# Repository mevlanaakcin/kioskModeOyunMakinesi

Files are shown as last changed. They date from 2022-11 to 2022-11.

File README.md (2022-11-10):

# kioskModeOyunMakinesi
Kiosk Modda çalışan eğlence amaçlı oyun makinesi<br>
<h3>PCB Tasarımı</h3><br>
Elektronik devre şeması ve PCB board tasarımı Eagle de tasarlandı.<br>





<h3>Yazılım</h3><br>
Yalım bölümü Atmega328-P işlemci kullanıldığından Raspberrypi ile tasarlanan kart arasında Serial haberleşme yapılmıştır. Kart üzerinde bulunan servo motorlar ile ödül dağıtım kanallarını kontrol edilmektedir. Görsel amaçlı kullanılan neopiksellerin yazılımsal kontrolleride yapılmıştır.

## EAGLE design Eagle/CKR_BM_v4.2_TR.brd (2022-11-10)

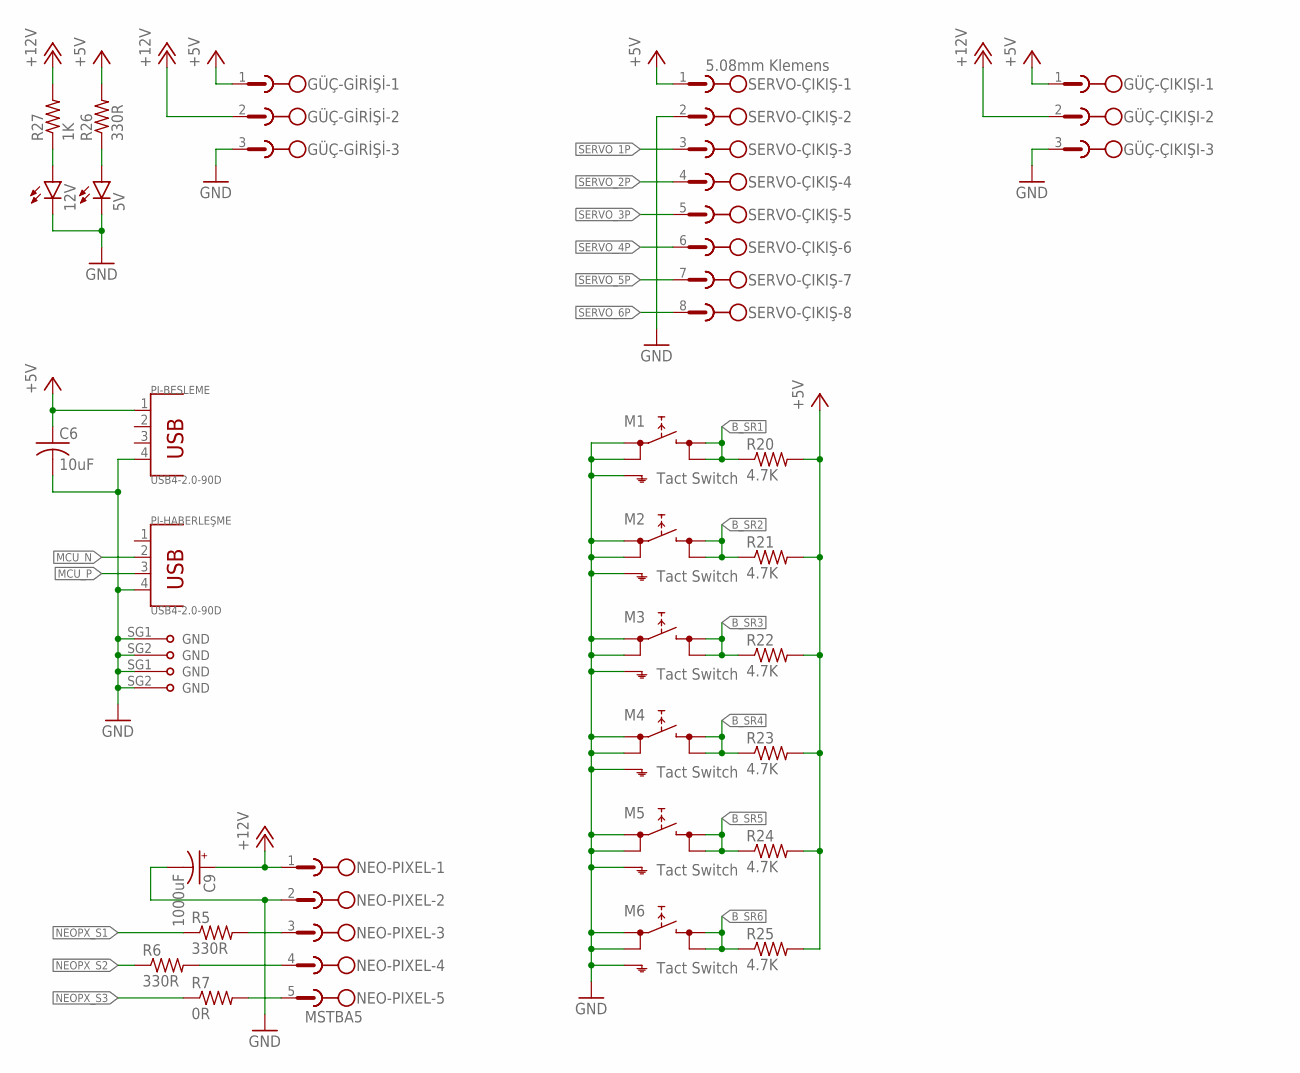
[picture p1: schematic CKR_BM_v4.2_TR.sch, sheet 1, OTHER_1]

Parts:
5V, 12V: LEDCHIP-LED0805; CHIP-LED0805
C6: 10uF; C0805
C9: 1000uF; 140CLH-1010
GÜÇ-GİRİŞİ: 5.08mm Klemens; MSTBA3
GÜÇ-ÇIKIŞI: 5.08mm Klemens; MSTBA3
M1, M2, M3, M4, M5, M6: Tact Switch; SKHMPXE010
NEO-PIXEL: MSTBA5
PI-BESLEME: USB4-2.0-90D; USB4+2P-2.0-90D
PI-HABERLEŞME: USB4-2.0-90D; USB4+2P-2.0-90D
R5, R6, R26: 330R; R0805
R7: 0R; R0805
R20, R21, R22, R23, R24, R25: 4.7K; R0805
R27: 1K; R0805
SERVO-ÇIKIŞ: 5.08mm Klemens; MSTBA8

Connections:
+5V: C6.1, GÜÇ-GİRİŞİ.1, GÜÇ-ÇIKIŞI.1, PI-BESLEME.1, R20.2, R21.2, R22.2, R23.2, R24.2, R25.2, R26.2, SERVO-ÇIKIŞ.1; also elsewhere on the board
+12V: C9.+, GÜÇ-GİRİŞİ.2, GÜÇ-ÇIKIŞI.2, NEO-PIXEL.1, R27.2; also elsewhere on the board
B_SR1: M1.3 (2.1), M1.4 (2.2), R20.1; also elsewhere on the board
B_SR2: M2.3 (2.1), M2.4 (2.2), R21.1; also elsewhere on the board
B_SR3: M3.3 (2.1), M3.4 (2.2), R22.1; also elsewhere on the board
B_SR4: M4.3 (2.1), M4.4 (2.2), R23.1; also elsewhere on the board
B_SR5: M5.3 (2.1), M5.4 (2.2), R24.1; also elsewhere on the board
B_SR6: M6.3 (2.1), M6.4 (2.2), R25.1; also elsewhere on the board
GND: 5V.C, 12V.C, C6.2, C9.-, GÜÇ-GİRİŞİ.3, GÜÇ-ÇIKIŞI.3, M1.1 (1.1), M1.2 (1.2), M1.5 (SH), M2.1 (1.1), M2.2 (1.2), M2.5 (SH), M3.1 (1.1), M3.2 (1.2), M3.5 (SH), M4.1 (1.1), M4.2 (1.2), M4.5 (SH), M5.1 (1.1), M5.2 (1.2), M5.5 (SH), M6.1 (1.1), M6.2 (1.2), M6.5 (SH), NEO-PIXEL.2, PI-BESLEME.4, PI-BESLEME.SG1 (GND), PI-BESLEME.SG2 (GND), PI-HABERLEŞME.4, PI-HABERLEŞME.SG1 (GND), PI-HABERLEŞME.SG2 (GND), SERVO-ÇIKIŞ.2; also elsewhere on the board
MCU_N: PI-HABERLEŞME.2; also elsewhere on the board
MCU_P: PI-HABERLEŞME.3; also elsewhere on the board
unnamed: NEO-PIXEL.3, R5.2
unnamed: NEO-PIXEL.4, R6.2
unnamed: NEO-PIXEL.5, R7.2
unnamed: 5V.A, R26.1
unnamed: 12V.A, R27.1
NEOPX_S1: R5.1; also elsewhere on the board
NEOPX_S2: R6.1; also elsewhere on the board
NEOPX_S3: R7.1; also elsewhere on the board
SERVO_1P: SERVO-ÇIKIŞ.3; also elsewhere on the board
SERVO_2P: SERVO-ÇIKIŞ.4; also elsewhere on the board
SERVO_3P: SERVO-ÇIKIŞ.5; also elsewhere on the board
SERVO_4P: SERVO-ÇIKIŞ.6; also elsewhere on the board
SERVO_5P: SERVO-ÇIKIŞ.7; also elsewhere on the board
SERVO_6P: SERVO-ÇIKIŞ.8; also elsewhere on the board

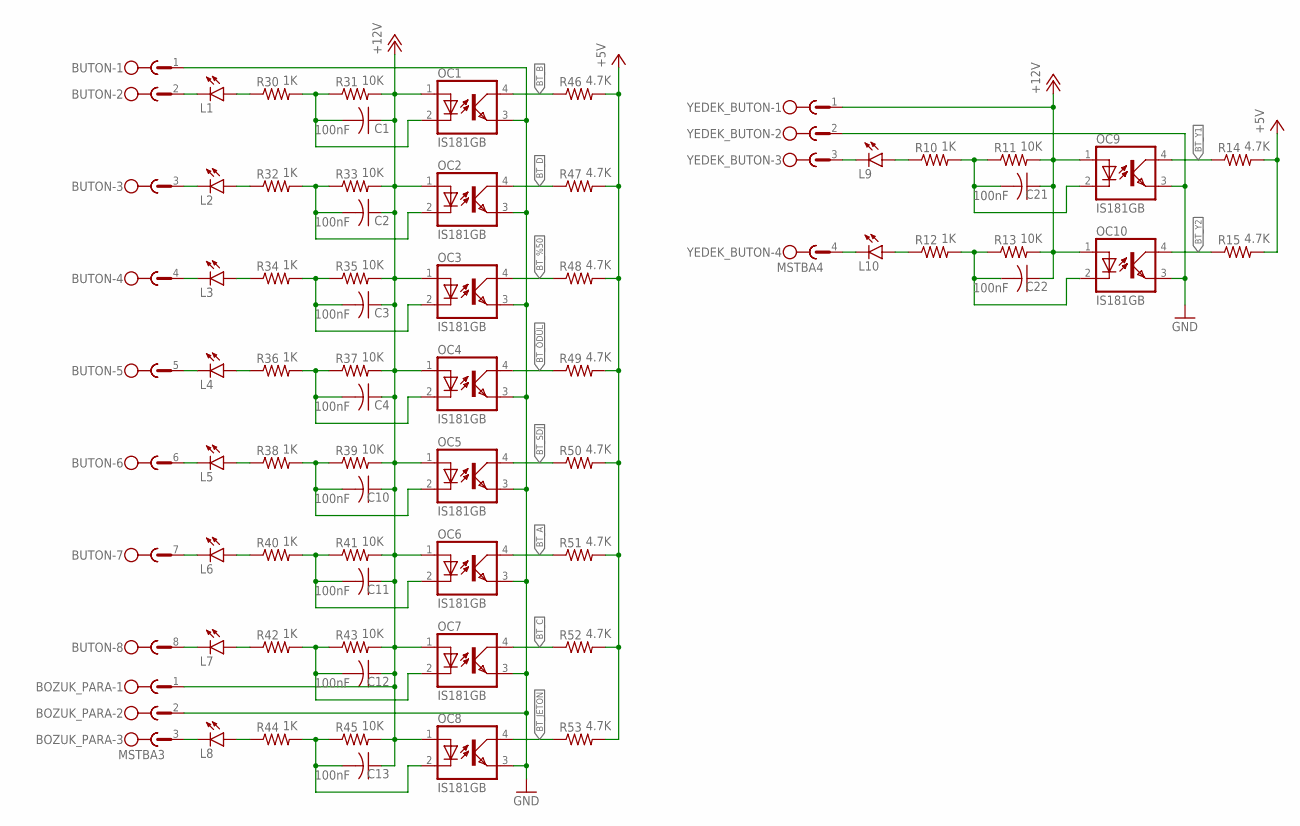
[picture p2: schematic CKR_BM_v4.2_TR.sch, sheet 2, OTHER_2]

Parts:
BOZUK_PARA: MSTBA3
BUTON: MSTBA8
C1, C2, C3, C4, C10, C11, C12, C13, C21, C22: 100nF; C0805
L1, L2, L3, L4, L5, L6, L7, L8, L9, L10: LEDCHIP-LED0805; CHIP-LED0805
OC1, OC2, OC3, OC4, OC5, OC6, OC7, OC8, OC9, OC10: IS181GB; SO-4
R10, R12, R30, R32, R34, R36, R38, R40, R42, R44: 1K; R0805
R11, R13, R31, R33, R35, R37, R39, R41, R43, R45: 10K; R0805
R14, R15, R46, R47, R48, R49, R50, R51, R52, R53: 4.7K; R0805
YEDEK_BUTON: MSTBA4

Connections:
+5V: R14.2, R15.2, R46.2, R47.2, R48.2, R49.2, R50.2, R51.2, R52.2, R53.2; also elsewhere on the board
+12V: BOZUK_PARA.1, C1.1, C2.1, C3.1, C4.1, C10.1, C11.1, C12.1, C13.1, C21.1, C22.1, OC1.1 (A), OC2.1 (A), OC3.1 (A), OC4.1 (A), OC5.1 (A), OC6.1 (A), OC7.1 (A), OC8.1 (A), OC9.1 (A), OC10.1 (A), R11.2, R13.2, R31.2, R33.2, R35.2, R37.2, R39.2, R41.2, R43.2, R45.2, YEDEK_BUTON.1; also elsewhere on the board
BT_%50: OC3.4 (COL), R48.1; also elsewhere on the board
BT_A: OC6.4 (COL), R51.1; also elsewhere on the board
BT_B: OC1.4 (COL), R46.1; also elsewhere on the board
BT_C: OC7.4 (COL), R52.1; also elsewhere on the board
BT_D: OC2.4 (COL), R47.1; also elsewhere on the board
BT_JETON: OC8.4 (COL), R53.1; also elsewhere on the board
BT_SDJ: OC5.4 (COL), R50.1; also elsewhere on the board
BT_Y1: OC9.4 (COL), R14.1; also elsewhere on the board
BT_Y2: OC10.4 (COL), R15.1; also elsewhere on the board
BT_ÖDÜL: OC4.4 (COL), R49.1; also elsewhere on the board
GND: BOZUK_PARA.2, BUTON.1, OC1.3 (EMIT), OC2.3 (EMIT), OC3.3 (EMIT), OC4.3 (EMIT), OC5.3 (EMIT), OC6.3 (EMIT), OC7.3 (EMIT), OC8.3 (EMIT), OC9.3 (EMIT), OC10.3 (EMIT), YEDEK_BUTON.2; also elsewhere on the board
unnamed: L1.A, R30.1
unnamed: C1.2, OC1.2 (C), R30.2, R31.1
unnamed: L9.A, R10.1
unnamed: BUTON.2, L1.C
unnamed: BOZUK_PARA.3, L8.C
unnamed: L2.A, R32.1
unnamed: C2.2, OC2.2 (C), R32.2, R33.1
unnamed: C21.2, OC9.2 (C), R10.2, R11.1
unnamed: BUTON.8, L7.C
unnamed: L3.A, R34.1
unnamed: C3.2, OC3.2 (C), R34.2, R35.1
unnamed: L9.C, YEDEK_BUTON.3
unnamed: BUTON.7, L6.C
unnamed: L4.A, R36.1
unnamed: C4.2, OC4.2 (C), R36.2, R37.1
unnamed: L10.A, R12.1
unnamed: BUTON.6, L5.C
unnamed: L5.A, R38.1
unnamed: C10.2, OC5.2 (C), R38.2, R39.1
unnamed: C22.2, OC10.2 (C), R12.2, R13.1
unnamed: BUTON.5, L4.C
unnamed: L6.A, R40.1
unnamed: C11.2, OC6.2 (C), R40.2, R41.1
unnamed: L10.C, YEDEK_BUTON.4
unnamed: BUTON.4, L3.C
unnamed: L7.A, R42.1
unnamed: C12.2, OC7.2 (C), R42.2, R43.1
unnamed: BUTON.3, L2.C
unnamed: L8.A, R44.1
unnamed: C13.2, OC8.2 (C), R44.2, R45.1

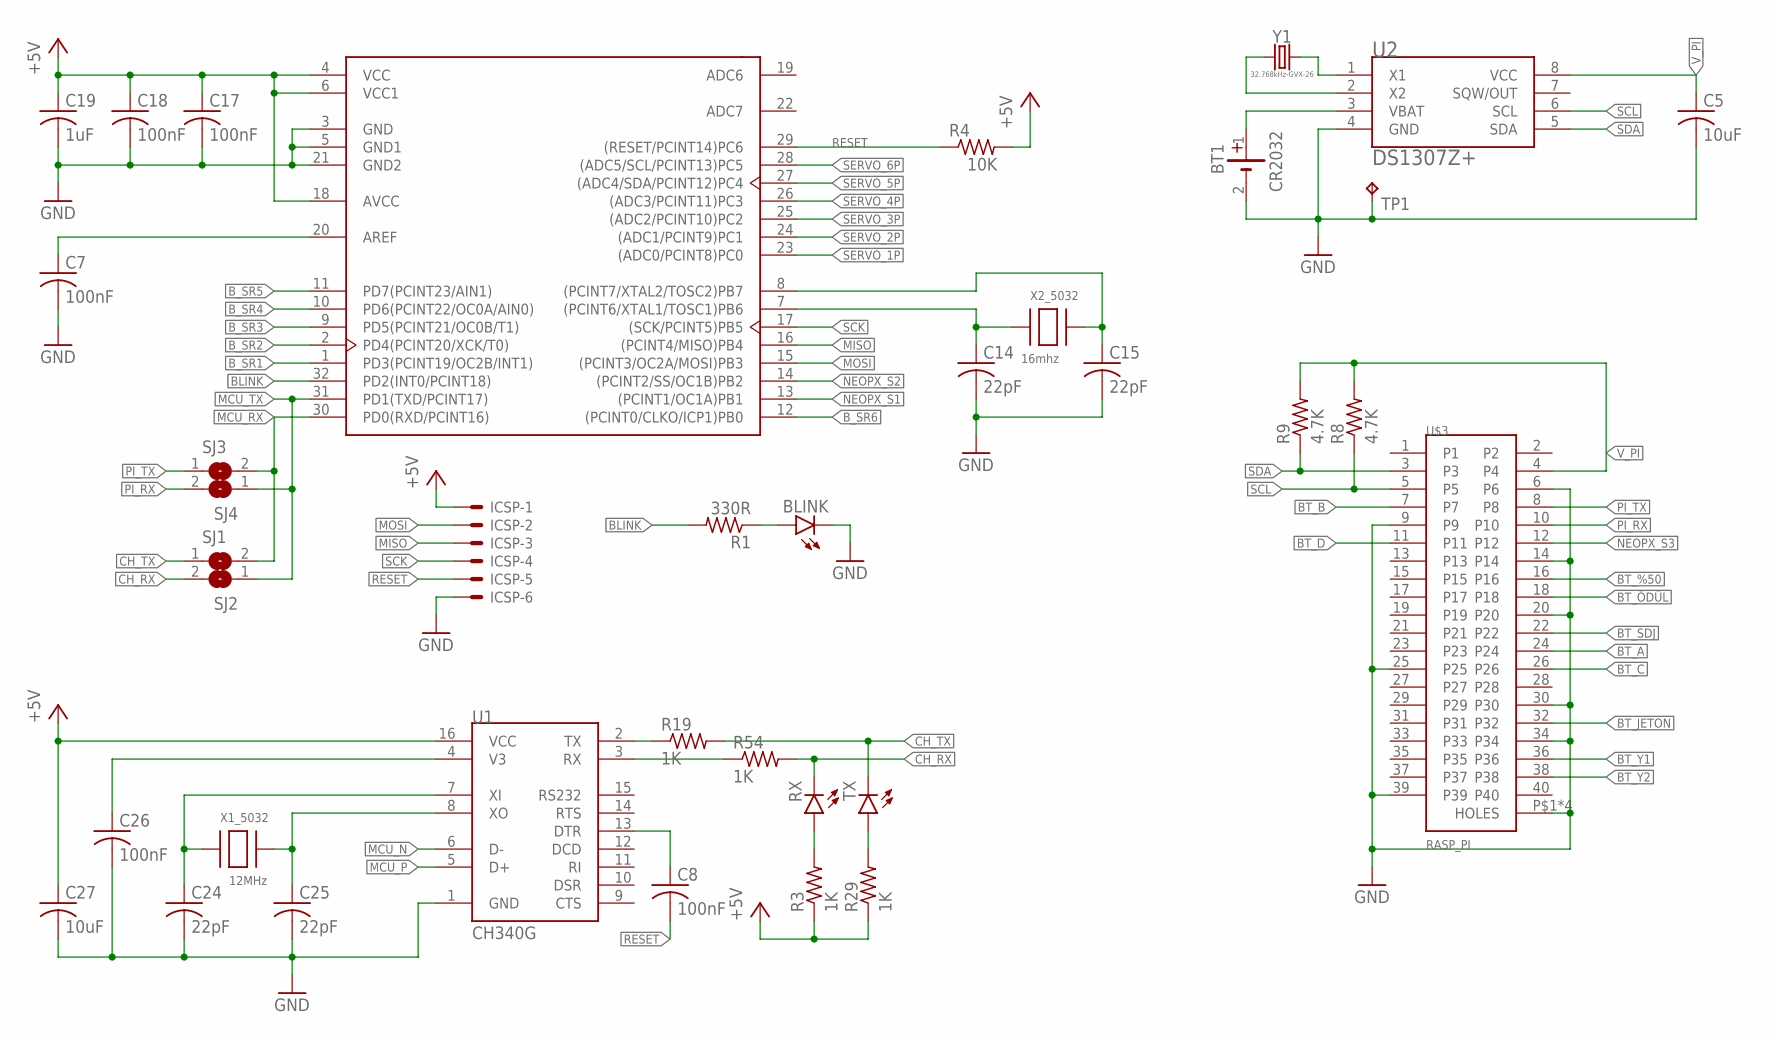
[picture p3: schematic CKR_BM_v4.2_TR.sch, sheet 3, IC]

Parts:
BLINK: LEDCHIP-LED0805; CHIP-LED0805
BT1: CR2032; 79528211
C5, C27: 10uF; C0805
C7, C8, C17, C18, C26: 100nF; C0805
C14, C15, C24, C25: 22pF; C0805
C19: 1uF; C0805
ICSP: C-GRID-06-70543; 70543-06
R1: 330R; R0805
R3, R19, R29, R54: 1K; R0805
R4: 10K; R0805
R8, R9: 4.7K; R0805
RX: LEDCHIP-LED0805; CHIP-LED0805
SJ1, SJ2, SJ3, SJ4: SJ
TP1: GND; TP15R
TX: LEDCHIP-LED0805; CHIP-LED0805
U1: CH340G; SOIC16
U2: DS1307Z+; SOIC-8N
U4: ATMEGA328P-AU; TQFP-32
U$3: RASP_PI
X1_5032: 12MHz; NX5032
X2_5032: 16mhz; NX5032
Y1: 32.768kHz-GVX-26; CRYSTAL-PTH-2X6-CYL

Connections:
+5V: C17.1, C18.1, C19.1, C27.1, ICSP.1, R3.1, R4.2, R29.1, U1.16 (VCC), U4.4 (VCC), U4.6 (VCC1), U4.18 (AVCC); also elsewhere on the board
BLINK: R1.2, U4.32 (PD2(INT0/PCINT18))
BT_%50: U$3.16; also elsewhere on the board
BT_A: U$3.24; also elsewhere on the board
BT_B: U$3.7; also elsewhere on the board
BT_C: U$3.26; also elsewhere on the board
BT_D: U$3.11; also elsewhere on the board
BT_JETON: U$3.32; also elsewhere on the board
BT_SDJ: U$3.22; also elsewhere on the board
BT_Y1: U$3.36; also elsewhere on the board
BT_Y2: U$3.38; also elsewhere on the board
BT_ÖDÜL: U$3.18; also elsewhere on the board
B_SR1: U4.1 (PD3(PCINT19/OC2B/INT1)); also elsewhere on the board
B_SR2: U4.2 (PD4(PCINT20/XCK/T0)); also elsewhere on the board
B_SR3: U4.9 (PD5(PCINT21/OC0B/T1)); also elsewhere on the board
B_SR4: U4.10 (PD6(PCINT22/OC0A/AIN0)); also elsewhere on the board
B_SR5: U4.11 (PD7(PCINT23/AIN1)); also elsewhere on the board
B_SR6: U4.12 ((PCINT0/CLKO/ICP1)PB0); also elsewhere on the board
CH_RX: R54.2, RX.C, SJ2.2
CH_TX: R19.2, SJ1.1, TX.C
GND: BLINK.C, BT1.2 (-), C5.2, C7.2, C14.2, C15.2, C17.2, C18.2, C19.2, C24.2, C25.2, C26.2, C27.2, ICSP.6, TP1.TP, U1.1 (GND), U2.4 (GND), U4.3 (GND), U4.5 (GND1), U4.21 (GND2), U$3.6, U$3.9, U$3.14, U$3.20, U$3.25, U$3.30, U$3.34, U$3.39, U$3.P$1 (HOLES), U$3.P$2 (HOLES), U$3.P$3 (HOLES), U$3.P$4 (HOLES); also elsewhere on the board
MCU_N: U1.6 (D-); also elsewhere on the board
MCU_P: U1.5 (D+); also elsewhere on the board
MCU_RX: SJ1.2, SJ3.2, U4.30 (PD0(RXD/PCINT16))
MCU_TX: SJ2.1, SJ4.1, U4.31 (PD1(TXD/PCINT17))
MISO: ICSP.3, U4.16 ((PCINT4/MISO)PB4)
MOSI: ICSP.2, U4.15 ((PCINT3/OC2A/MOSI)PB3)
unnamed: BT1.1 (+), U2.3 (VBAT)
unnamed: U2.2 (X2), Y1.1
unnamed: U2.1 (X1), Y1.2
unnamed: R3.2, RX.A
unnamed: R29.2, TX.A
unnamed: C14.1, U4.7 ((PCINT6/XTAL1/TOSC1)PB6), X2_5032.P$1
unnamed: C8.1, U1.13 (DTR)
unnamed: C26.1, U1.4 (V3)
unnamed: C24.1, U1.7 (XI), X1_5032.P$1
unnamed: C25.1, U1.8 (XO), X1_5032.P$2
unnamed: R19.1, U1.2 (TX)
unnamed: R54.1, U1.3 (RX)
unnamed: BLINK.A, R1.1
unnamed: C7.1, U4.20 (AREF)
unnamed: C15.1, U4.8 ((PCINT7/XTAL2/TOSC2)PB7), X2_5032.P$2
NEOPX_S1: U4.13 ((PCINT1/OC1A)PB1); also elsewhere on the board
NEOPX_S2: U4.14 ((PCINT2/SS/OC1B)PB2); also elsewhere on the board
NEOPX_S3: U$3.12; also elsewhere on the board
PI_RX: SJ4.2, U$3.10
PI_TX: SJ3.1, U$3.8
RESET: C8.2, ICSP.5, R4.1, U4.29 ((RESET/PCINT14)PC6)
SCK: ICSP.4, U4.17 ((SCK/PCINT5)PB5)
SCL: R8.1, U2.6 (SCL), U$3.5
SDA: R9.1, U2.5 (SDA), U$3.3
SERVO_1P: U4.23 ((ADC0/PCINT8)PC0); also elsewhere on the board
SERVO_2P: U4.24 ((ADC1/PCINT9)PC1); also elsewhere on the board
SERVO_3P: U4.25 ((ADC2/PCINT10)PC2); also elsewhere on the board
SERVO_4P: U4.26 ((ADC3/PCINT11)PC3); also elsewhere on the board
SERVO_5P: U4.27 ((ADC4/SDA/PCINT12)PC4); also elsewhere on the board
SERVO_6P: U4.28 ((ADC5/SCL/PCINT13)PC5); also elsewhere on the board
V_PI: C5.1, R8.2, R9.2, U2.8 (VCC), U$3.4

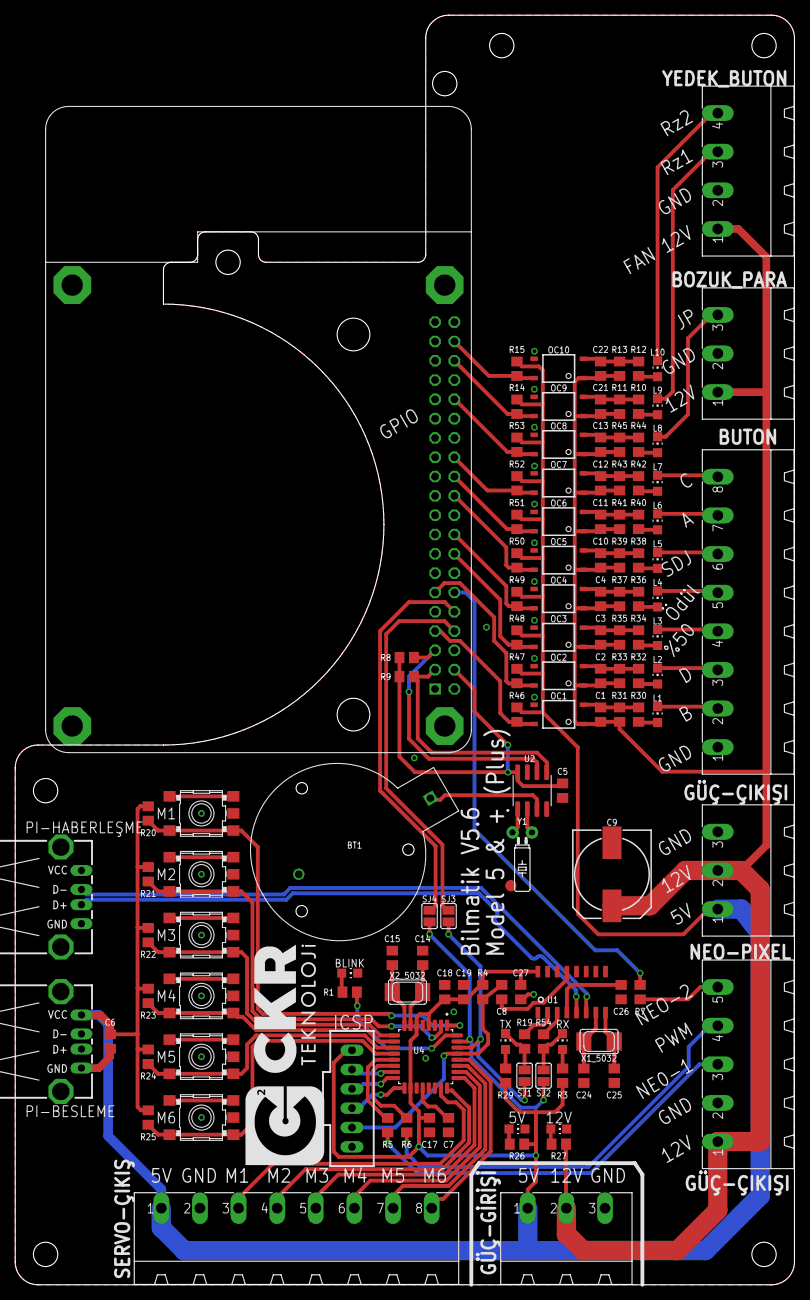
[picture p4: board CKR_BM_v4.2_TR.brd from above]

Board: 2 copper layers, 102.5 x 167.0 mm, 127 parts (1 on the bottom side), 94 nets.

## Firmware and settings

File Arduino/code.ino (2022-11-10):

#include<EEPROM.h>
#include<Servo.h>
//Butonların pinleri belirlendi
#define buton1 3
#define buton2 4
#define buton3 5
#define buton4 6
#define buton5 7
#define buton6 8
char key[10];
int servo_delay = 500; // Servo motorun ödülü bırakması için tayin edilen süre
int baslangic = 150;
int bitis = 50;
//Servo isimleri tayin edildi
Servo  servo1;
Servo  servo2;
Servo  servo3;
Servo  servo4;
Servo  servo5;
Servo  servo6;
//EEPROM temizleme fonksiyonu
void eepromClear() {
  for (int i = 0; i < EEPROM.length(); i++) {
    EEPROM.update(i, 0);
  }
}
//EEPROM kayıt fonksiyonu
void eepromWrite() {
  for (int i = 0; i < 10; i++) {
    EEPROM.write(i, key[i]);
    delay(50);
  }
}
//EEPROM güncelleme fonksiyonu
void eepromUpdate() {
  for (int i = 0; i < 10; i++) {
    EEPROM.update(i, key[i]);
    delay(50);
  }
}
//EEPROM okuma fonksiyonu
String eepromRead() {
  String data_eeprom;
  for (int k = 0; k < 10; ++k) {
    char a = char(EEPROM.read(k));
    delay(50);
    data_eeprom += a;
  }
  return data_eeprom;
}


void setup() {
  Serial.begin(9600);
  //Butonlar giriş olarak ayarlandı
  pinMode(buton1, INPUT); pinMode(buton2, INPUT); pinMode(buton3, INPUT);
  pinMode(buton4, INPUT); pinMode(buton5, INPUT); pinMode(buton6, INPUT);

  //Servo çıkış pinleri ayarlandı
  //servo1.attach(A0); servo2.attach(A1); servo3.attach(A2);
  //servo4.attach(A3); servo5.attach(A4); servo6.attach(A5);

  //Servo motorlar 0 derece konumuna çekildi
  // servo1.write(baslangic); servo2.write(baslangic); servo3.write(baslangic);
  //servo4.write(baslangic); servo5.write(baslangic); servo6.write(baslangic);
  servo1.attach(A0); servo1.write(baslangic); delay(100); servo1.detach();
  servo2.attach(A1); servo2.write(baslangic); delay(100); servo2.detach();
  servo3.attach(A2); servo3.write(baslangic); delay(100); servo3.detach();
  servo4.attach(A3); servo4.write(baslangic); delay(100); servo4.detach();
  servo5.attach(A4); servo5.write(baslangic); delay(100); servo5.detach();
  servo6.attach(A5); servo6.write(baslangic); delay(100); servo6.detach();
}



void loop() {
  if (Serial.available() > 0) {
    String data = Serial.readStringUntil('\n');
    if (data.toInt() == 101) {
      servo1.attach(A0);
      servo1.write(bitis);
      delay(servo_delay);
      servo1.write(baslangic);
      delay(servo_delay);
      servo1.detach();
      Serial.println("0");
    }
    else if (data.toInt() == 202) {
      servo2.write(bitis);
      servo2.attach(A1);
      delay(servo_delay);
      servo2.write(baslangic);
      delay(servo_delay);
      servo2.detach();
      Serial.println("0");
    }
    else if (data.toInt() == 303) {
      servo3.attach(A2);
      servo3.write(bitis);
      delay(servo_delay);
      servo3.write(baslangic);
      delay(servo_delay);
      servo3.detach();
      Serial.println("0");
    }
    else if (data.toInt() == 404) {
      servo4.attach(A3);
      servo4.write(bitis);
      delay(servo_delay);
      servo4.write(baslangic);
      delay(servo_delay);
      servo4.detach();
      Serial.println("0");
    }
    else if (data.toInt() == 505) {
      servo5.attach(A4);
      servo5.write(bitis);
      delay(servo_delay);
      servo5.write(baslangic);
      delay(servo_delay);
      servo5.detach();
      Serial.println("0");
    }
    else if (data.toInt() == 606) {
      servo6.attach(A5);
      servo6.write(bitis);
      delay(servo_delay);
      servo6.write(baslangic);
      delay(servo_delay);
      servo6.detach();
      Serial.println("0");
    }
    else if (data.toInt() == 707) {
      eepromClear();
      Serial.println("0");
    }
    else if (data.toInt() == 808) {
      String a = eepromRead();
      Serial.println(a);
    }
    else if (data.length() == 11) {
      for (int y = 0; y < 10; y++) {
        key[y] = data.charAt(y);
      }
      String val = eepromRead();
      if (val.length() > 9) {
        eepromUpdate();
      }
      else {
        eepromWrite();
      }
      Serial.println("0");
    }
    else {

    }

  }

  else {
    if (digitalRead(buton1) == LOW) {
      servo1.attach(A0);
      servo1.write(bitis);
      delay(servo_delay);
      servo1.write(baslangic);
      delay(servo_delay);
      servo1.detach();
    }
    else if (digitalRead(buton2) == LOW) {
      servo2.attach(A1);
      servo2.write(bitis);
      delay(servo_delay);
      servo2.write(baslangic);
      delay(servo_delay);
      servo2.detach();
    }
    else if (digitalRead(buton3) == LOW) {
      servo3.attach(A2);
      servo3.write(bitis);
      delay(servo_delay);
      servo3.write(baslangic);
      delay(servo_delay);
      servo3.detach();
    }
    else if (digitalRead(buton4) == LOW) {
      servo4.attach(A3);
      servo4.write(bitis);
      delay(servo_delay);
      servo4.write(baslangic);
      delay(servo_delay);
      servo4.detach();
    }
    else if (digitalRead(buton5) == LOW) {
      servo5.attach(A4);
      servo5.write(bitis);
      delay(servo_delay);
      servo5.write(baslangic);
      delay(servo_delay);
      servo5.detach();
    }
    else if (digitalRead(buton6) == LOW) {
      servo6.attach(A5);
      servo6.write(bitis);
      delay(servo_delay);
      servo6.write(baslangic);
      delay(servo_delay);
      servo6.detach();
    }
    else {
      //servo1.attach(A0); servo1.write(baslangic); delay(100); servo1.detach();
      //servo2.attach(A1); servo2.write(baslangic); delay(100); servo2.detach();
      // servo3.attach(A2); servo3.write(baslangic); delay(100); servo3.detach();
      // servo4.attach(A3); servo4.write(baslangic); delay(100); servo4.detach();
      // servo5.attach(A4); servo5.write(baslangic); delay(100); servo5.detach();
      // servo6.attach(A5); servo6.write(baslangic); delay(100); servo6.detach();

    }

  }
}

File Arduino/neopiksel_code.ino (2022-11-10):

#include<Servo.h>
#include <Adafruit_NeoPixel.h>
#define tetik 2
#define PIN 6
#define NUMPIXELS 11
int durum = 1;
String read_data = "";
int speed_neo = 100;
int show_time = 500;
int cisim = 10;
/*
  0----Paper
  1----Plastic
  8----Glass
  9----Organic
  10----Metal
*/
int dizi[5] = {0, 1, 8, 9, 10};
Adafruit_NeoPixel neo = Adafruit_NeoPixel(NUMPIXELS, PIN, NEO_GRB + NEO_KHZ800);
Servo mecservo;
Servo inservo;
Servo outservo;
void selection_close() {
  for (int i = 0; i < 6; i++) {
    neo.setPixelColor(dizi[i] , 0, 0, 0);
    neo.show(); delay(speed_neo);
  }
}
void selection() {

  for (int i = 0; i < 6; i++) {
    neo.setPixelColor(dizi[i] , 255, 255, 255);
    if (i != 0) {
      neo.setPixelColor(dizi[i - 1] , 0, 0, 0);
    } neo.show(); delay(speed_neo);
  }

}

void recycle_white() {
  for (int i = 2; i < 8; i++) {
    neo.setPixelColor(i , 255, 255, 255);
  } neo.show(); delay(speed_neo);
}
int parla() {

  for (int i = 2; i < 8; i++) {
    for (int j = 10; j < 255; j++) {
      neo.setPixelColor(i, 0, j, 0);
    } if (i != 7) {
      neo.setPixelColor(i + 1, 255, 255, 255);
    } neo.show(); delay(speed_neo);
  }
}
int son() {

  for (int i = 2; i < 8; i++) {
    for (int j = 255; j > 10; j--) {
      neo.setPixelColor(i, 0, j, 0);
    } neo.show(); delay(speed_neo);
  }
}
void recycle() {
  parla();
  son();
}

int paper = 0;
int cardboard = 30;
int glass = 60;
int metal = 90;
int plastic = 120;
int trash = 150;
void setup() {
  neo.setBrightness(100); //Parlaklık
  neo.begin();
  neo.show();
  mecservo.attach(10);
  inservo.attach(9);
  outservo.attach(11);
  pinMode(tetik, OUTPUT);
  Serial.begin(9600);
  inservo.write(0);
  outservo.write(0);
  mecservo.write(paper);
}


void loop() {
  while (durum == 1) {
    recycle();
    int butonread = digitalRead(tetik);
    delay(150);
    if (butonread == 1) {
      Serial.println("Sensor");
      inservo.write(90);
      delay(1000);
      recycle_white();
      durum = 0;
      break;
    }
  }

  if (Serial.available() > 0) {

    read_data = Serial.readStringUntil('\n');
    if (read_data == "cardboard") {
      cisim = 0;
    }
    else if (read_data == "glass") {
      cisim = 1;
    }

    else if (read_data == "metal") {
      cisim = 2;
    }
    else if (read_data == "paper") {
      cisim = 3;
    }
    else if (read_data == "plastic") {
      cisim = 4;
    }
    else if (read_data == "trash") {
      cisim = 5;
    }
    else{
      cisim=10;
    }




    switch (cisim) {
      case 0:
        neo.setPixelColor(dizi[0] , 0, 255, 0);
        neo.setPixelColor(dizi[1] , 0, 0, 0);
        neo.setPixelColor(dizi[2] , 0, 0, 0);
        neo.setPixelColor(dizi[3] , 0, 0, 0);
        neo.setPixelColor(dizi[4] , 0, 0, 0);
        neo.show(); delay(show_time);
        mecservo.write(cardboard);
        delay(1000);
        outservo.write(90);
        delay(2000);
        outservo.write(0);
        delay(2500);
        mecservo.write(paper);
        delay(1000);
        inservo.write(0);
        delay(500);
        durum = 1;
        cisim=10;
        selection_close();
        break;
      case 1:
        neo.setPixelColor(dizi[0] , 0, 0, 0);
        neo.setPixelColor(dizi[1] , 0, 0, 0);
        neo.setPixelColor(dizi[2] , 0, 255, 0);
        neo.setPixelColor(dizi[3] , 0, 0, 0);
        neo.setPixelColor(dizi[4] , 0, 0, 0);
        neo.show(); delay(show_time);
        mecservo.write(glass);
        delay(1000);
        outservo.write(90);
        delay(2000);
        outservo.write(0);
        delay(2500);
        mecservo.write(paper);
        delay(1000);
        inservo.write(0);
        delay(500);
        durum = 1;
        cisim=10;
        selection_close();
        break;
      case 2:
        neo.setPixelColor(dizi[0] , 0, 0, 0);
        neo.setPixelColor(dizi[1] , 0, 0, 0);
        neo.setPixelColor(dizi[2] , 0, 0, 0);
        neo.setPixelColor(dizi[3] , 0, 0, 0);
        neo.setPixelColor(dizi[4] , 0, 255, 0);
        neo.show(); delay(show_time);
        mecservo.write(metal);
        delay(1000);
        outservo.write(90);
        delay(2000);
        outservo.write(0);
        delay(2500);
        mecservo.write(paper);
        delay(1000);
        inservo.write(0);
        delay(500);
        durum = 1;
        cisim=10;
        selection_close();
        break;
      case 3:
        neo.setPixelColor(dizi[0] , 0, 255, 0);
        neo.setPixelColor(dizi[1] , 0, 0, 0);
        neo.setPixelColor(dizi[2] , 0, 0, 0);
        neo.setPixelColor(dizi[3] , 0, 0, 0);
        neo.setPixelColor(dizi[4] , 0, 0, 0);
        neo.show(); delay(show_time);
        mecservo.write(paper);
        delay(1000);
        outservo.write(90);
        delay(2000);
        outservo.write(0);
        delay(2500);
        mecservo.write(paper);
        delay(1000);
        inservo.write(0);
        delay(500);
        durum = 1;
        cisim=10;
        selection_close();
        break;
      case 4:
        neo.setPixelColor(dizi[0] , 0, 0, 0);
        neo.setPixelColor(dizi[1] , 0, 255, 0);
        neo.setPixelColor(dizi[2] , 0, 0, 0);
        neo.setPixelColor(dizi[3] , 0, 0, 0);
        neo.setPixelColor(dizi[4] , 0, 0, 0);
        neo.show(); delay(show_time);
        mecservo.write(plastic);
        delay(1000);
        outservo.write(90);
        delay(2000);
        outservo.write(0);
        delay(2500);
        mecservo.write(paper);
        delay(1000);
        inservo.write(0);
        delay(500);
        durum = 1;
        selection_close();
        break;
        cisim=10;
      case 5:
        neo.setPixelColor(dizi[0] , 0, 0, 0);
        neo.setPixelColor(dizi[1] , 0, 0, 0);
        neo.setPixelColor(dizi[2] , 0, 0, 0);
        neo.setPixelColor(dizi[3] , 255, 255, 255);
        neo.setPixelColor(dizi[4] , 0, 0, 0);
        neo.show(); delay(show_time);
        mecservo.write(trash);
        delay(1000);
        outservo.write(90);
        delay(2000);
        outservo.write(0);
        delay(2500);
        mecservo.write(paper);
        delay(1000);
        inservo.write(0);
        delay(500);
        selection_close();
        durum = 1;
        cisim=10;
        break;
    }

  }
  else {
    for (int i = 0; i < 20; i++) {
      selection();
    }
  }


}

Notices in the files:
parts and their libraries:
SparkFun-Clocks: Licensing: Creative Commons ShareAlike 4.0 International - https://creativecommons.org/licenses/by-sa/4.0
